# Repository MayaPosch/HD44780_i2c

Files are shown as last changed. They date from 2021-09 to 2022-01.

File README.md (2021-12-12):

# HD44780-compatible I2C adapter #

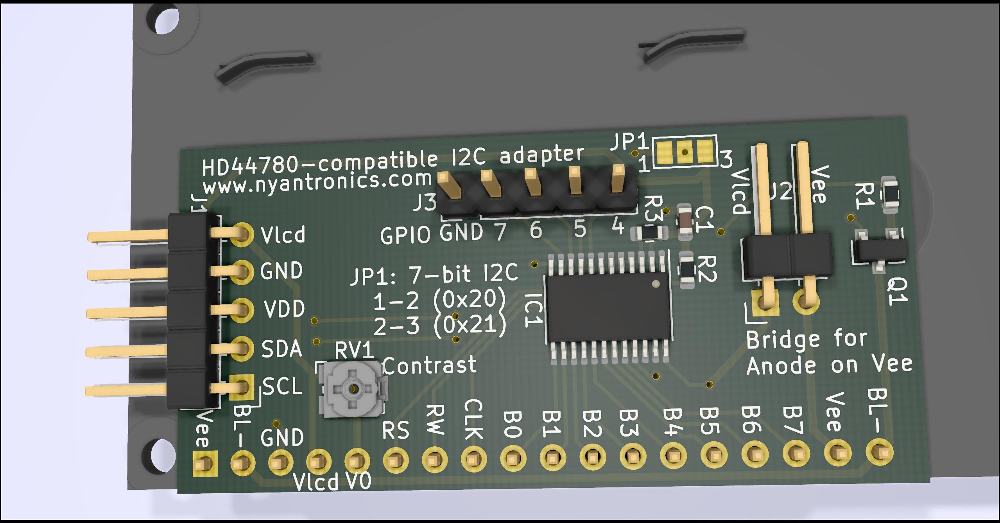
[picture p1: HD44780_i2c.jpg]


This project is an I2C expander module based around a Texas Instruments TCA6416A I2C GPIO expander. It allows for interfacing with a variety of 14 to 16-pin, HD44780-compatible displays:

- 14-pin without backlight.
- 16-pin with A/K backlight pins after pin 14.
- 16-pin with A/K backlight pins before pin 1.
- 16-pin with Vee negative bias voltage output on pin 16 instead of backlight ground.

This adapter is compatible with both 3.3V and 5V I2C bus levels. The 5-pin MCU/MPU side header has the following connections:

1. **Vlcd:** LCD-side voltage. This is 5V for a 5V display.
2. **GND:** Ground connection.
3. **VDD:** I2C bus voltage. This is 3.3V for a 3.3V MCU.
4. **SDA:** I2C data line. At MCU level voltage.
5. **SCL:** I2C clock line. At MCU level voltage.

## I2C address ##

Default I2C 7-bit address is 0x20, set with JP1 (1-2 connected). To use the alternate 0x21 address, cut the connection on JP1 between pads 1 & 2, and connect 2-3.

## GPIO header ##

Four GPIO pins from the I2C expander are broken out into a 5-pin header (J3). These can be freely used, limited by the TCA6416A's capabilities.

## Vlcd-Vee backlight ##

When a display is connected that does not use pin 16 for Vee (negative bias), but instead expects a 5V backlight supply voltage on this, connect the `Vlcd-Vee` connector with a jumper.

## Backlight enable ##

The backlight on/off state is controlled by GPIO 0 of the TCA6416A via Q1.

## Contrast adjustment ##

For contrast adjustment, a potentiometer on the board is provided.

## TODO ##

This is currently a prototype design. It's likely that some things may not fully work as intended yet.

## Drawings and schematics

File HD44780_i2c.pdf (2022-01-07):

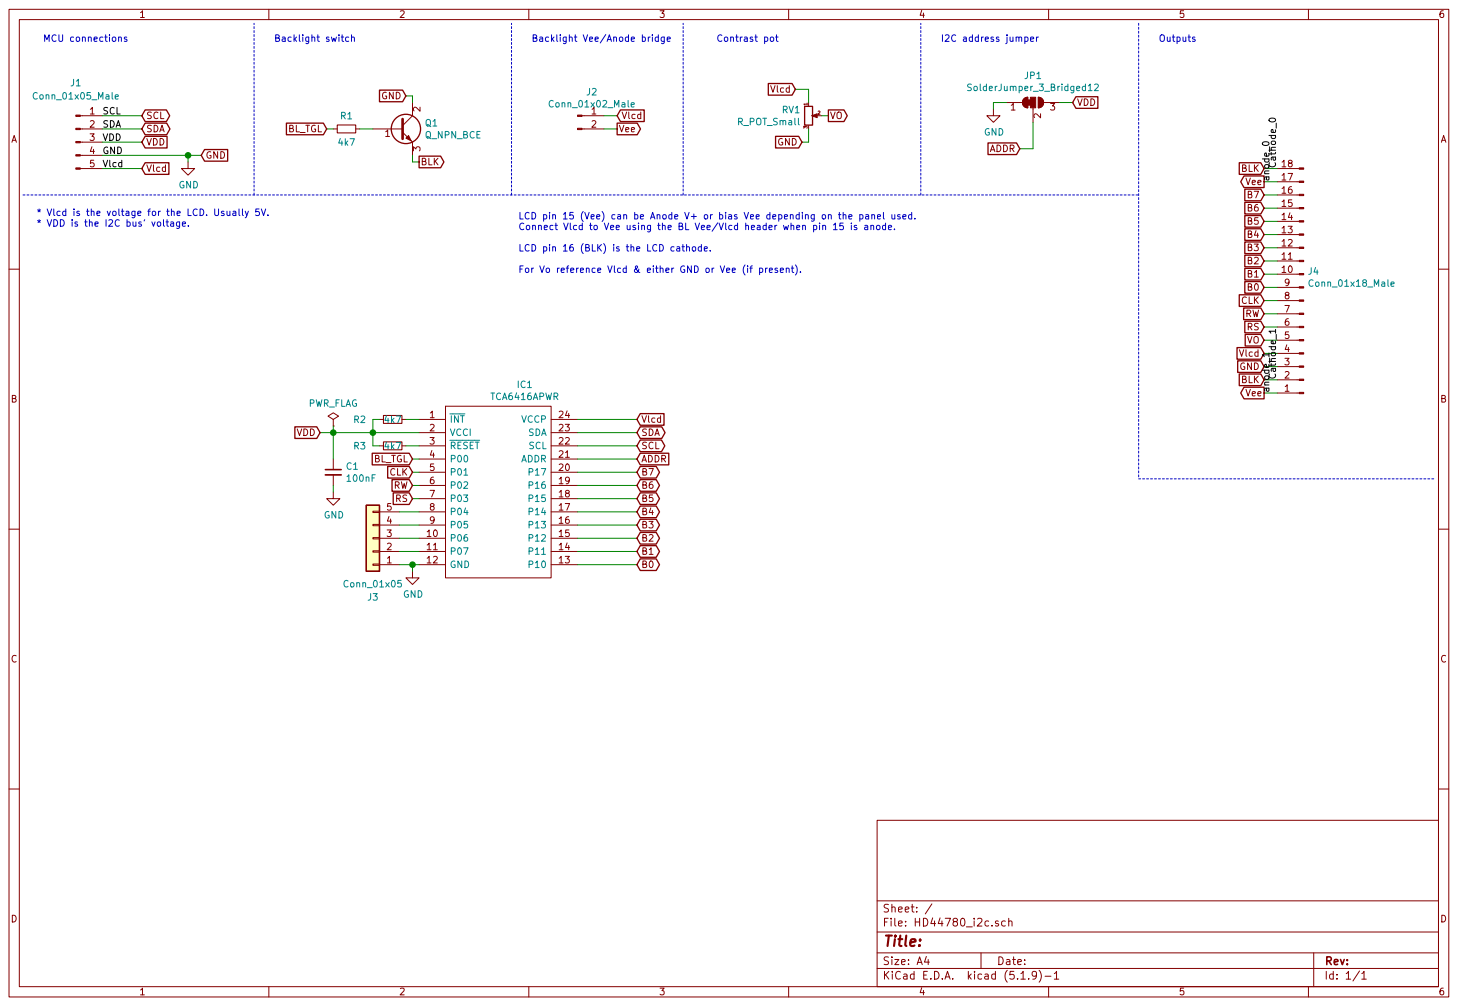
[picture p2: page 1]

Vlcd BLK GND GND

* Vlcd is the voltage for the LCD. Usually 5V.
* VDD is the I2C bus' voltage.

LCD pin 15 (Vee) can be Anode V+ or bias Vee depending on the panel used.
Connect Vlcd to Vee using the BL Vee/Vlcd header when pin 15 is anode.

LCD pin 16 (BLK) is the LCD cathode.

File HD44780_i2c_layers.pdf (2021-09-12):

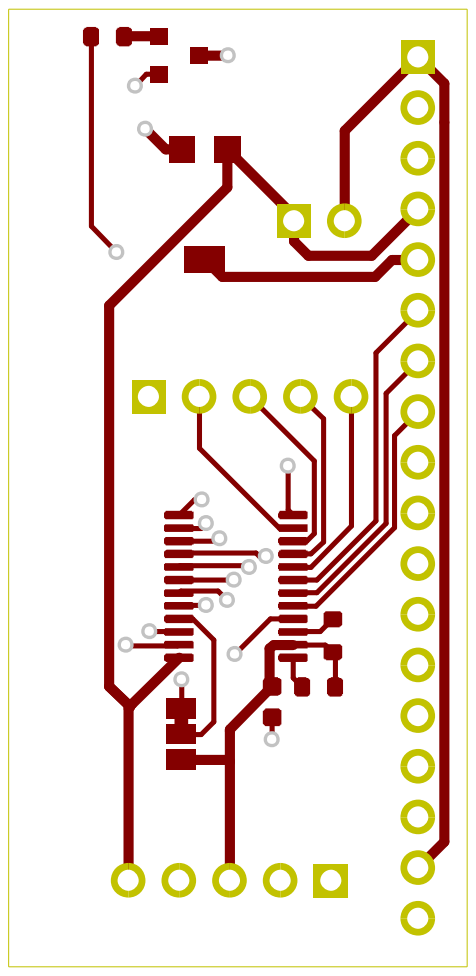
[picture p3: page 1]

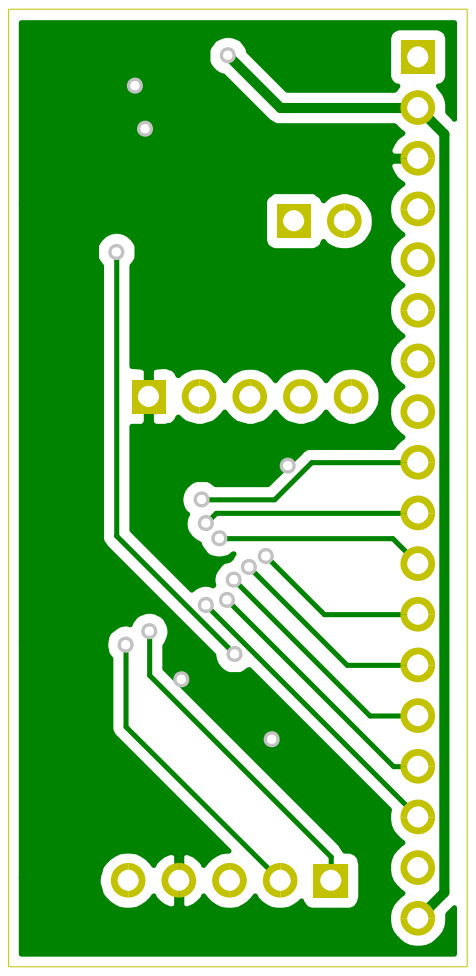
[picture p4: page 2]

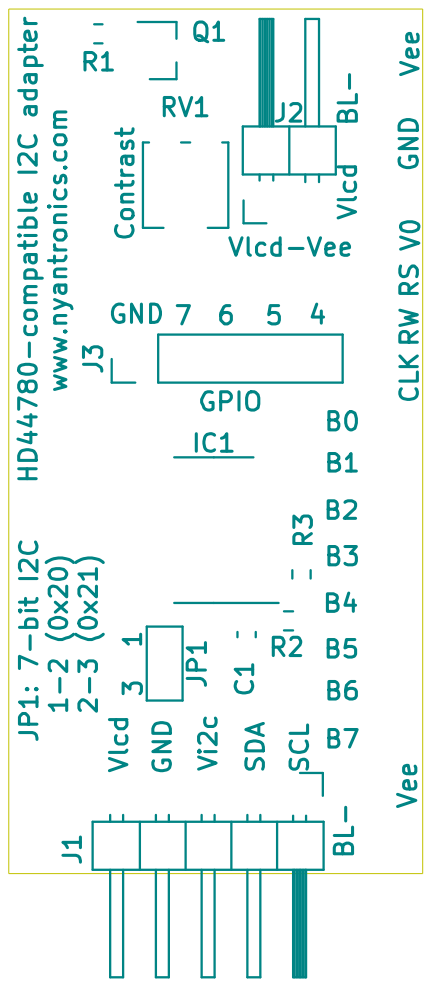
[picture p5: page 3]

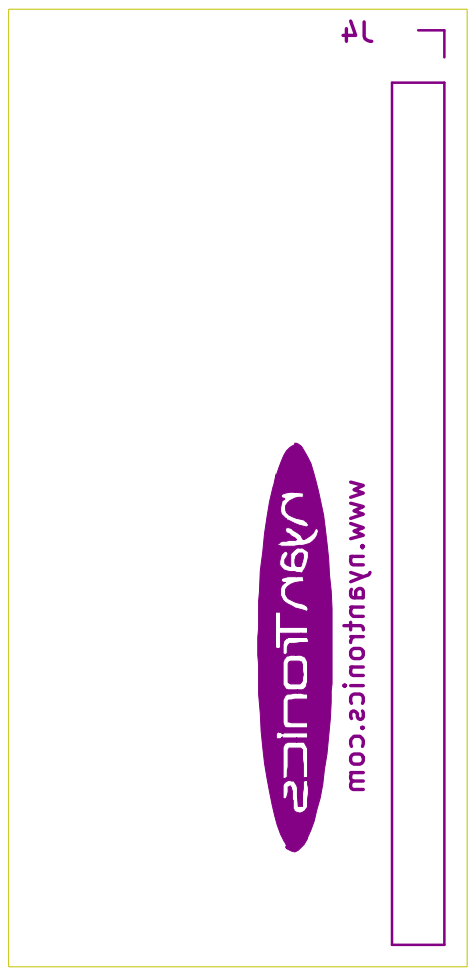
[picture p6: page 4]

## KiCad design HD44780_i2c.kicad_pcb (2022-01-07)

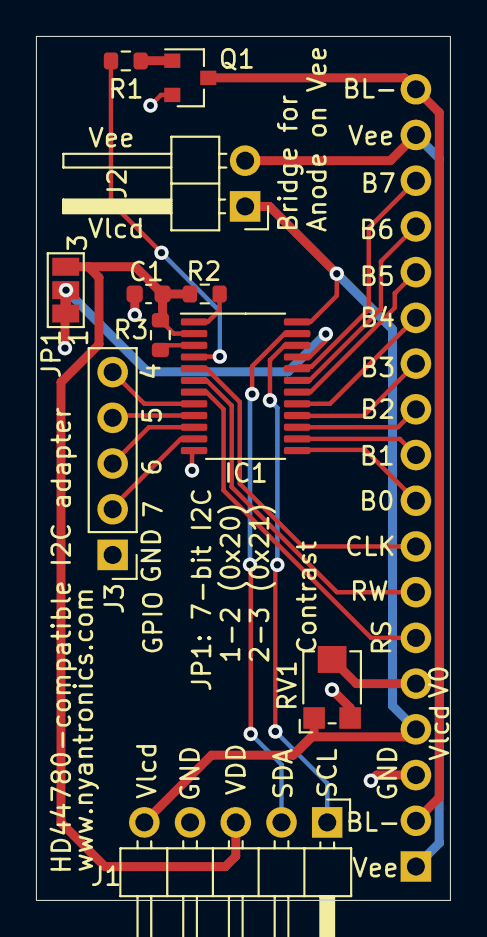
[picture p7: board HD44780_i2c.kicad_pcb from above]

Board: 2 copper layers, 23.0 x 48.0 mm, 12 parts (1 on the bottom side), 28 nets.

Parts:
C1: 100nF; C_0603_1608Metric
IC1: TCA6416APWR; TSSOP-24_4.4x7.8mm_P0.65mm
J1: Conn_01x05_Male; PinHeader_1x05_P2.54mm_Horizontal
J2: Conn_01x02_Male; PinHeader_1x02_P2.54mm_Horizontal
J3: Conn_01x05; PinHeader_1x05_P2.54mm_Vertical
J4: Conn_01x18_Male; PinHeader_1x18_P2.54mm_Vertical
JP1: SolderJumper_3_Bridged12; SolderJumper-3_P1.3mm_Bridged12_Pad1.0x1.5mm_NumberLabels
Q1: Q_NPN_BCE; SOT-23
R1, R2, R3: 4k7; R_0603_1608Metric
RV1: R_POT_Small; Potentiometer_Bourns_TC33X_Vertical

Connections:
ADDR: IC1.21, JP1.2
B0: IC1.13, J4.9
B1: IC1.14, J4.10
B2: IC1.15, J4.11
B3: IC1.16, J4.12
B4: IC1.17, J4.13
B5: IC1.18, J4.14
B6: IC1.19, J4.15
B7: IC1.20, J4.16
BLK: J4.2, J4.18, Q1.3
BL_TGL: IC1.4, R1.2
CLK: IC1.5, J4.8
GND: C1.2, IC1.12, J1.4, J3.1, J4.3, JP1.1, Q1.2, RV1.3
unnamed: IC1.1, R2.1
unnamed: IC1.3, R3.1
unnamed: IC1.8, J3.5
unnamed: IC1.9, J3.4
unnamed: IC1.10, J3.3
unnamed: IC1.11, J3.2
unnamed: Q1.1, R1.1
RS: IC1.7, J4.6
RW: IC1.6, J4.7
SCL: IC1.22, J1.1
SDA: IC1.23, J1.2
VDD: C1.1, IC1.2, J1.3, JP1.3, R2.2, R3.2
VO: J4.5, RV1.2
Vee: J2.2, J4.1, J4.17
Vlcd: IC1.24, J1.5, J2.1, J4.4, RV1.1

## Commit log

2021-05-10 Initial commit of WIP.
    [HD44780_i2c.kicad_pcb, HD44780_i2c.sch]
2021-09-12 Replace main IC with Ti version. Reroute PCB. Update silkscreen.
    [HD44780_i2c.kicad_pcb, HD44780_i2c.sch]
2021-09-12 Add silkscreen docu.
    [HD44780_i2c.kicad_pcb]
2021-12-12 Correctly orient main header. Update layout & routing.
    [HD44780_i2c.kicad_pcb, HD44780_i2c.sch]
2021-12-12 Change location of jumper pad. Change Vi2c to VDD.
    [HD44780_i2c.kicad_pcb, HD44780_i2c.sch]
2021-12-12 Update board render.
2021-12-12 Improve clearance between address pad and components.
    [HD44780_i2c.kicad_pcb]
2021-12-12 Add HTML BOM file.
2021-12-12 Replace trimmer with most cost-effective variant.
    [HD44780_i2c.kicad_pcb, HD44780_i2c.sch]
2022-01-07 Update BL cathode naming and schematic comments.
    [HD44780_i2c.kicad_pcb, HD44780_i2c.sch]
2022-01-07 Update schematic PDF.
